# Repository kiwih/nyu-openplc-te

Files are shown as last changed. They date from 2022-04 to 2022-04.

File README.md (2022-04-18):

# NYU OpenPLC Trojan Edition (TE)

This repository contains NYU's implementation of the OpenPLC hardware. 
Several important modifications are included, notably, a socket for a second
microcontroller (a Raspberry Pi Pico) which can act as a 'Hardware Trojan'.
Different Hardware Trojan capabilities can be enabled and disabled depending on the configuration of a number of jumpers located around the PCB.

There are a small number of known issues with the v0.1 board. 
These include the usage of a now-obsolete accelerometer, and poor component
choice for on-board power measurement circuitry.

These will be remedied for version 0.2 of this work.

This PCB was used in the paper,
"Detecting Hardware Trojans in PCBs Using Side Channel Loopbacks"
by Hammond Pearce, Virinchi Roy Surabhi, Prashanth Krishnamurthy,
Joshua Trujillo, Ramesh Karri, and Farshad Khorrami.
Published in IEEE TVLSI, 2022.

## Repository contents

`/final-outputs-v0.1` - this includes the schematic files, BOM CSVs, PDF layout files, and final production gerbers of the PCB manufactured for use in the paper.

`/kicad-files-v0.1` - this contains the KiCAD project used to make the project.

## New versions of the PCB

Newer versions (v0.2 and above) are currently under active development and will be released through this repository upon validation.

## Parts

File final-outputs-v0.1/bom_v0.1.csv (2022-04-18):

Designator | Comment | Footprint | Manufacturer | Vendor
C1 | 220uF | Capacitor_SMD:CP_Elec_10x10 |  | C134519
C2 | 220uF | Capacitor_SMD:CP_Elec_10x10 |  | C134519
C3 | 180uF | Capacitor_SMD:CP_Elec_6.3x7.7 |  | C413657
C4 | 180uF | Capacitor_SMD:CP_Elec_6.3x7.7 |  | C413657
C5 | 4.7uF | Capacitor_SMD:C_0805_2012Metric |  | C1779
C6 | 100nF | Capacitor_SMD:C_0805_2012Metric |  | C49678
C7 | 100nF | Capacitor_SMD:C_0805_2012Metric |  | C49678
C8 | 1nF | Capacitor_SMD:C_0805_2012Metric |  | C46653
C9 | 100nF | Capacitor_SMD:C_0805_2012Metric |  | C49678
C10 | 1nF | Capacitor_SMD:C_0805_2012Metric |  | C46653
C11 | 100nF | Capacitor_SMD:C_0805_2012Metric |  | C49678
C12 | 100nF | Capacitor_SMD:C_0805_2012Metric |  | C49678
C13 | 100nF | Capacitor_SMD:C_0805_2012Metric |  | C49678
C14 | 100nF | Capacitor_SMD:C_0805_2012Metric |  | C49678
C15 | 100nF | Capacitor_SMD:C_0805_2012Metric |  | C49678
C16 | 100nF | Capacitor_SMD:C_0805_2012Metric |  | C49678
C17 | 100nF | Capacitor_SMD:C_0805_2012Metric |  | C49678
C18 | 4.7uf | Capacitor_SMD:C_0805_2012Metric |  | C1779
C19 | 1nF | Capacitor_SMD:C_0805_2012Metric |  | C46653
C20 | 100n | Capacitor_SMD:C_0805_2012Metric |  | C49678
C21 | 100nF | Capacitor_SMD:C_0805_2012Metric |  | C49678
C22 | 100n | Capacitor_SMD:C_0805_2012Metric |  | C49678
C23 | 100nf | Capacitor_SMD:C_0805_2012Metric |  | C49678
C24 | 22uf | Capacitor_SMD:C_0805_2012Metric |  | C45783
C25 | 22uf | Capacitor_SMD:C_0805_2012Metric |  | C45783
C26 | 4.7uF | Capacitor_SMD:C_0805_2012Metric |  | C1779
C27 | 100nF | Capacitor_SMD:C_0805_2012Metric |  | C49678
D1 | B5819W | Diode_SMD:D_SOD-123 |  | C8598
D2 | B5819W | Diode_SMD:D_SOD-123 |  | C8598
D3 | B5819W | Diode_SMD:D_SOD-123 |  | C8598
D4 | B5819W | Diode_SMD:D_SOD-123 |  | C8598
D5 | B5819W | Diode_SMD:D_SOD-123 |  | C8598
D6 | SS54 | Diode_SMD:D_SMA |  | C22452
D7 | LED | LED_SMD:LED_0805_2012Metric |  | C2297
D11 | LED | LED_SMD:LED_0805_2012Metric |  | C2297
D12 | LED | LED_SMD:LED_0805_2012Metric |  | C2297
D13 | LED | LED_SMD:LED_0805_2012Metric |  | C2297
D14 | LED | LED_SMD:LED_0805_2012Metric |  | C2297
D15 | LED | LED_SMD:LED_0805_2012Metric |  | C2297
D16 | LED | LED_SMD:LED_0805_2012Metric |  | C2297
D17 | LED | LED_SMD:LED_0805_2012Metric |  | C2297
D18 | LED | LED_SMD:LED_0805_2012Metric |  | C2297
D20 | LED | LED_SMD:LED_0805_2012Metric |  | C2297
D21 | LED | LED_SMD:LED_0805_2012Metric |  | C2293
D22 | LED | LED_SMD:LED_0805_2012Metric |  | C2293
K1 | G6S-2 | Relay_SMD:Relay_DPDT_Omron_G6S-2F |  | C397130
K2 | G6S-2 | Relay_SMD:Relay_DPDT_Omron_G6S-2F |  | C397130
K3 | G6S-2 | Relay_SMD:Relay_DPDT_Omron_G6S-2F |  | C397130
K4 | G6S-2 | Relay_SMD:Relay_DPDT_Omron_G6S-2F |  | C397130
L1 | 68uH | kiwih_kicad:L_10x11.5mm_H4mm |  | C497902
L2 | 3.3uH | kiwih_kicad:L_7.1x6.6_H3 |  | C207839
Q1 | 2N7002 | Package_TO_SOT_SMD:SOT-23 |  | C8545
Q2 | 2N7002 | Package_TO_SOT_SMD:SOT-23 |  | C8545
Q3 | 2N7002 | Package_TO_SOT_SMD:SOT-23 |  | C8545
Q4 | 2N7002 | Package_TO_SOT_SMD:SOT-23 |  | C8545
R1 | 1k | Resistor_SMD:R_0805_2012Metric |  | C17513
R2 | 1k | Resistor_SMD:R_0805_2012Metric |  | C17513
R3 | 1k | Resistor_SMD:R_0805_2012Metric |  | C17513
R4 | 1k | Resistor_SMD:R_0805_2012Metric |  | C17513
R5 | 120R | Resistor_SMD:R_0805_2012Metric |  | C17437
R9 | 100k | Resistor_SMD:R_0805_2012Metric |  | C17407
R10 | 100k | Resistor_SMD:R_0805_2012Metric |  | C17407
R11 | 100k | Resistor_SMD:R_0805_2012Metric |  | C17407
R12 | 100k | Resistor_SMD:R_0805_2012Metric |  | C17407
R13 | 16k | Resistor_SMD:R_0805_2012Metric |  | C17490
R14 | 16k | Resistor_SMD:R_0805_2012Metric |  | C17490
R15 | 16k | Resistor_SMD:R_0805_2012Metric |  | C17490
R16 | 16k | Resistor_SMD:R_0805_2012Metric |  | C17490
R17 | 10k | Resistor_SMD:R_0805_2012Metric |  | C17414
R18 | 10k | Resistor_SMD:R_0805_2012Metric |  | C17414
R19 | 10k | Resistor_SMD:R_0805_2012Metric |  | C17414
R20 | 10k | Resistor_SMD:R_0805_2012Metric |  | C17414
R21 | 10k | Resistor_SMD:R_0805_2012Metric |  | C17414
R22 | 10k | Resistor_SMD:R_0805_2012Metric |  | C17414
R23 | 10k | Resistor_SMD:R_0805_2012Metric |  | C17414
R24 | 10k | Resistor_SMD:R_0805_2012Metric |  | C17414
R25 | 20k | Resistor_SMD:R_0805_2012Metric |  | C4328
R26 | 20K | Resistor_SMD:R_0805_2012Metric |  | C4328
R27 | 5K | Resistor_SMD:R_0805_2012Metric |  | C4328
R28 | 5K | Resistor_SMD:R_0805_2012Metric |  | C4328
R29 | 10K | Resistor_SMD:R_0805_2012Metric |  | C17414
R30 | 10K | Resistor_SMD:R_0805_2012Metric |  | C17414
R31 | 10K | Resistor_SMD:R_0805_2012Metric |  | C17414
R32 | 10K | Resistor_SMD:R_0805_2012Metric |  | C17414
R33 | 10K | Resistor_SMD:R_0805_2012Metric |  | C17414
R34 | 10K | Resistor_SMD:R_0805_2012Metric |  | C17414
R35 | 100R | Resistor_SMD:R_0805_2012Metric |  | C17408
R36 | 100R | Resistor_SMD:R_0805_2012Metric |  | C17408
R37 | 120R | Resistor_SMD:R_0805_2012Metric |  | C17437
R38 | 120R | Resistor_SMD:R_0805_2012Metric |  | C17437
R39 | 120R | Resistor_SMD:R_0805_2012Metric |  | C17437
R40 | 120R | Resistor_SMD:R_0805_2012Metric |  | C17437
R41 | 10k | Resistor_SMD:R_0805_2012Metric |  | C17414
R42 | 10k | Resistor_SMD:R_0805_2012Metric |  | C17414
R43 | DNF | Resistor_SMD:R_0805_2012Metric
R44 | 120R | Resistor_SMD:R_0805_2012Metric |  | C17437
R45 | DNF | Resistor_SMD:R_0805_2012Metric
R46 | 120R | Resistor_SMD:R_0805_2012Metric |  | C17437
R47 | 120R | Resistor_SMD:R_0805_2012Metric |  | C17437
R48 | 120R | Resistor_SMD:R_0805_2012Metric |  | C17437
R50 | 0 | Resistor_SMD:R_0805_2012Metric |  | C17477
R51 | 10K | Resistor_SMD:R_0805_2012Metric |  | C17414
R52 | 10K | Resistor_SMD:R_0805_2012Metric |  | C17414
U1 | LM2596S-5 | Package_TO_SOT_SMD:TO-263-5_TabPin3 |  | C10002
U2 | LTV-247 | Package_SO:SOP-16_4.4x10.4mm_P1.27mm |  | C115451
U3 | ULN2003A | Package_SO:SOIC-16_3.9x9.9mm_P1.27mm |  | C7512
U4 | ADS1115IDGS | Package_SO:TSSOP-10_3x3mm_P0.5mm |  | C37593
U5 | SP3485EN | Package_SO:SOIC-8_3.9x4.9mm_P1.27mm |  | C8963
U6 | ACS712xLCTR-05B | Package_SO:SOIC-8_3.9x4.9mm_P1.27mm |  | C44471
U7 | AMS1117-3.3 | Package_TO_SOT_SMD:SOT-223-3_TabPin2 |  | C6186
U8 | ACS712xLCTR-05B | Package_SO:SOIC-8_3.9x4.9mm_P1.27mm |  | C44471
U9 | EL357N | kiwih_kicad:SOP-4_4.1x4.4mm_P2.54mm |  | C6649
U10 | ADS1115IDGS | Package_SO:TSSOP-10_3x3mm_P0.5mm |  | C37593
U11 | FXOS8700CQ | kiwih_kicad:QFN-16_5.3.5.3_3x3_Pitch0.5mm |  | C432308
U12 | ACS712xLCTR-05B | Package_SO:SOIC-8_3.9x4.9mm_P1.27mm |  | C44471

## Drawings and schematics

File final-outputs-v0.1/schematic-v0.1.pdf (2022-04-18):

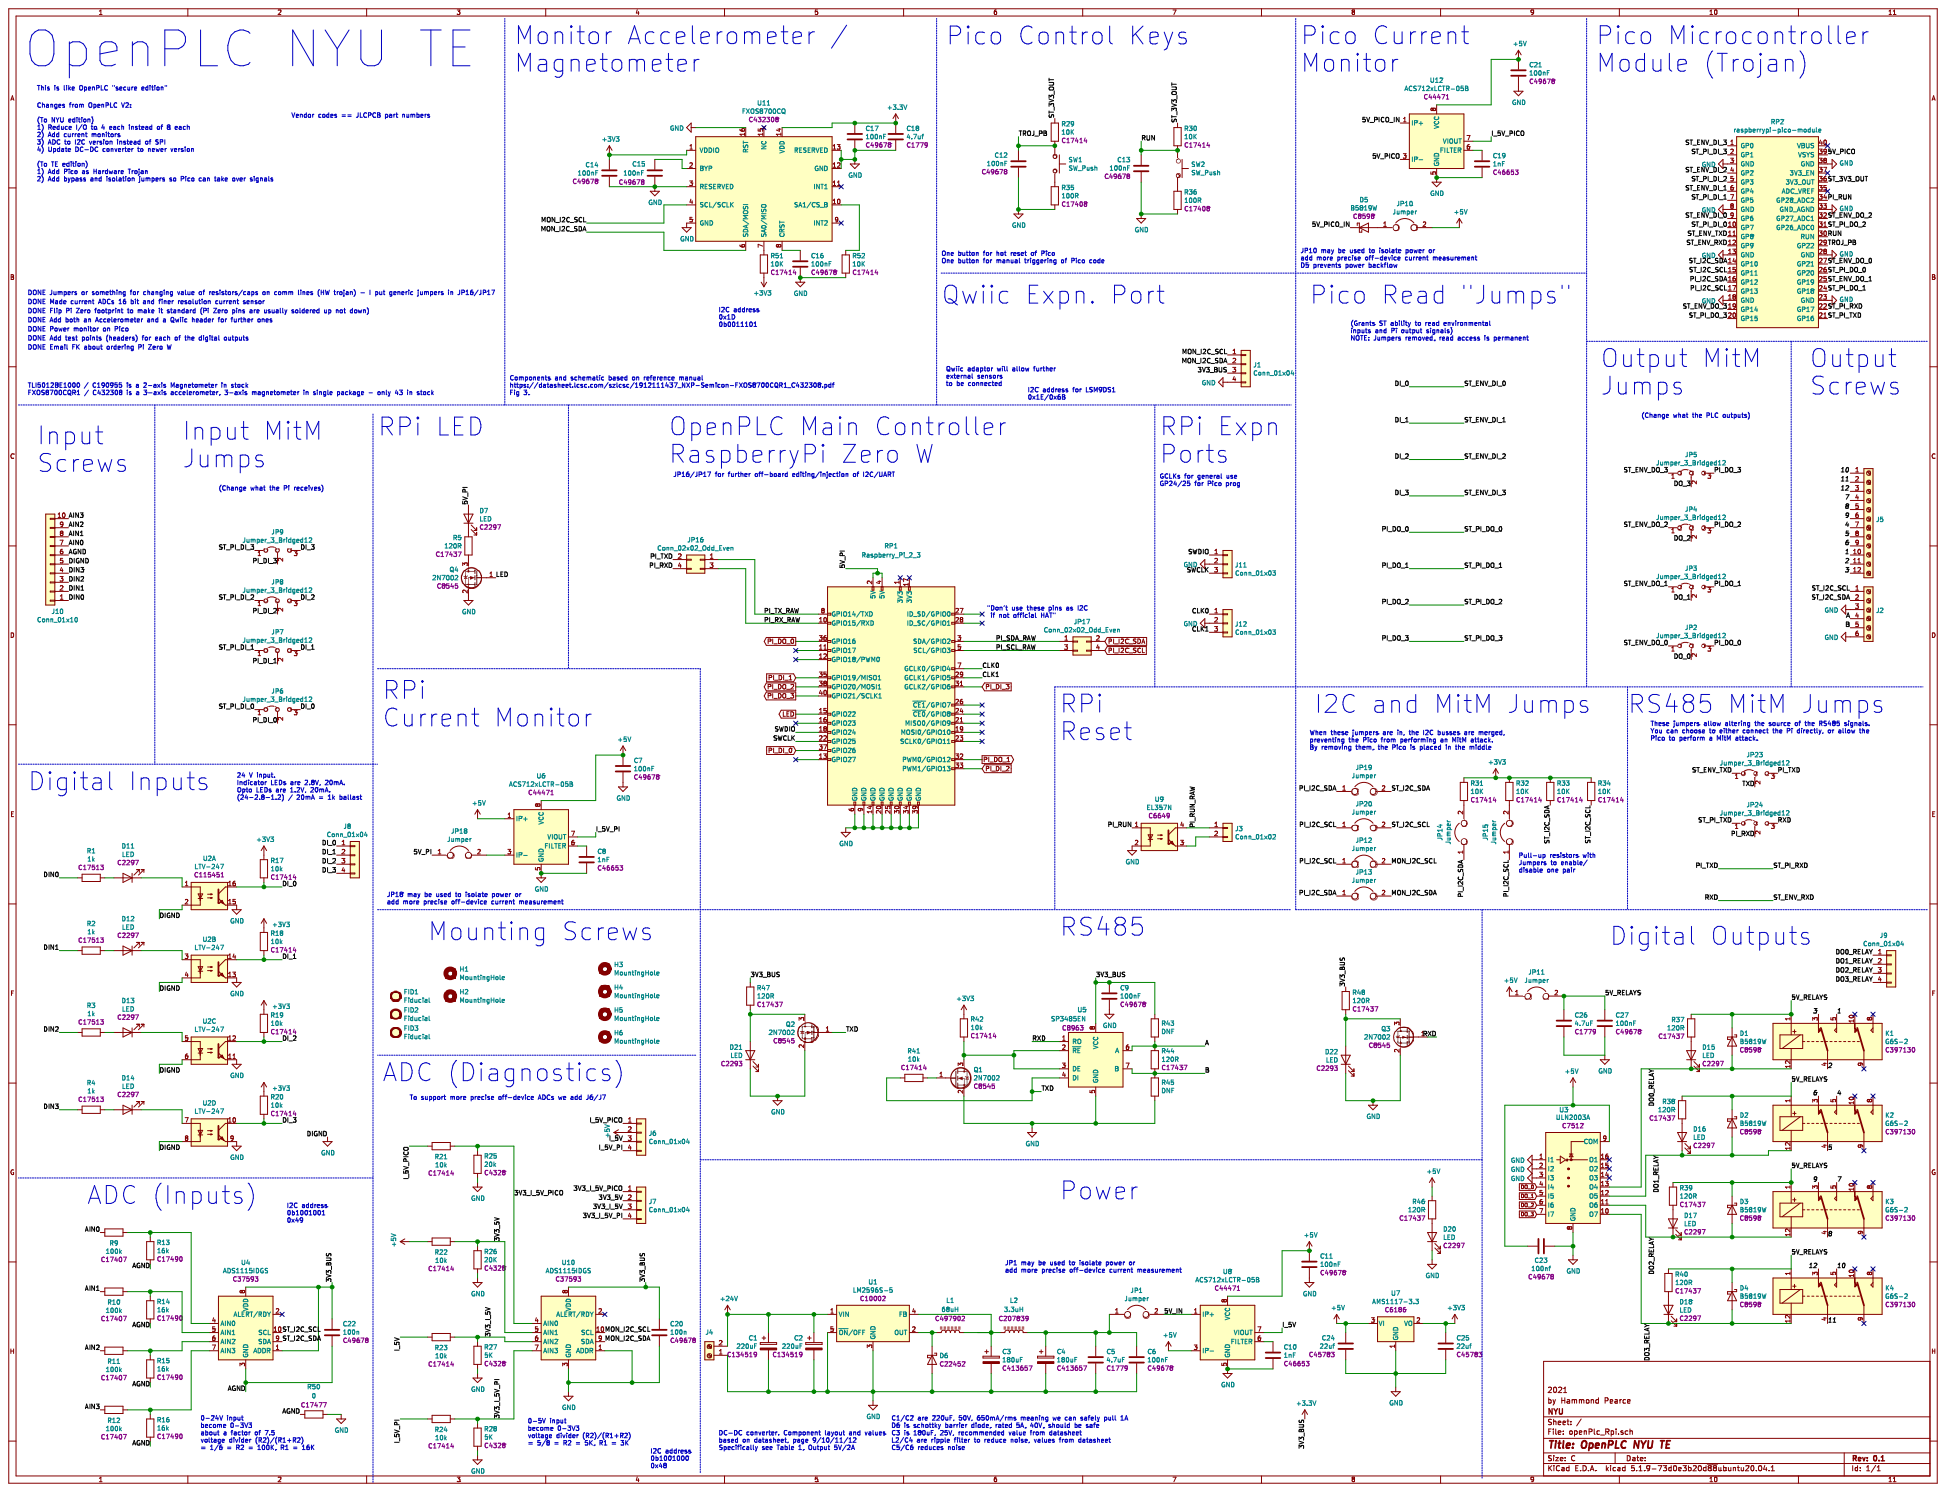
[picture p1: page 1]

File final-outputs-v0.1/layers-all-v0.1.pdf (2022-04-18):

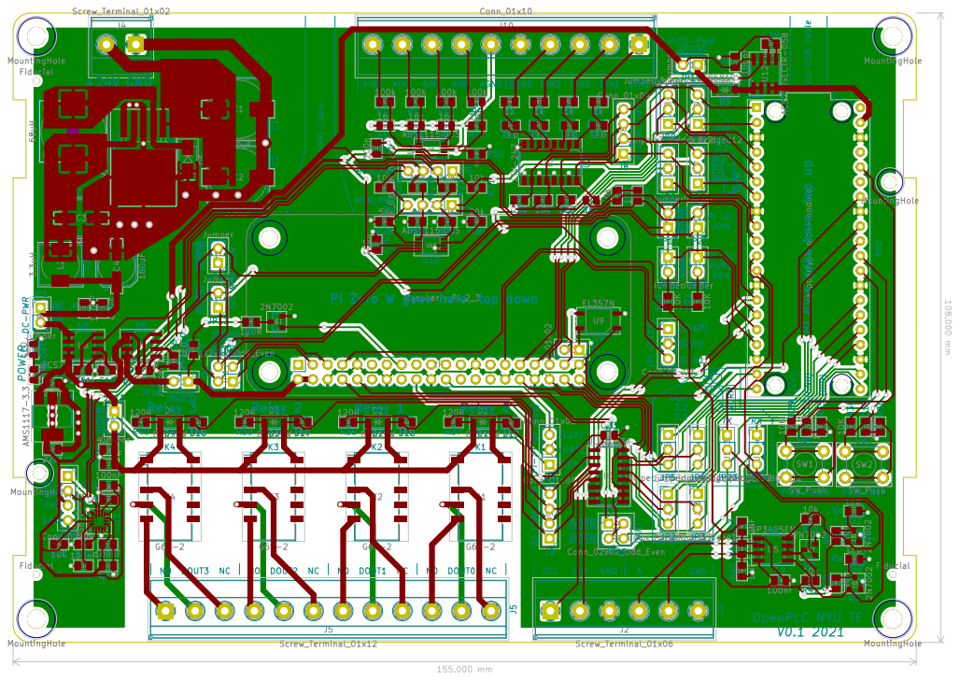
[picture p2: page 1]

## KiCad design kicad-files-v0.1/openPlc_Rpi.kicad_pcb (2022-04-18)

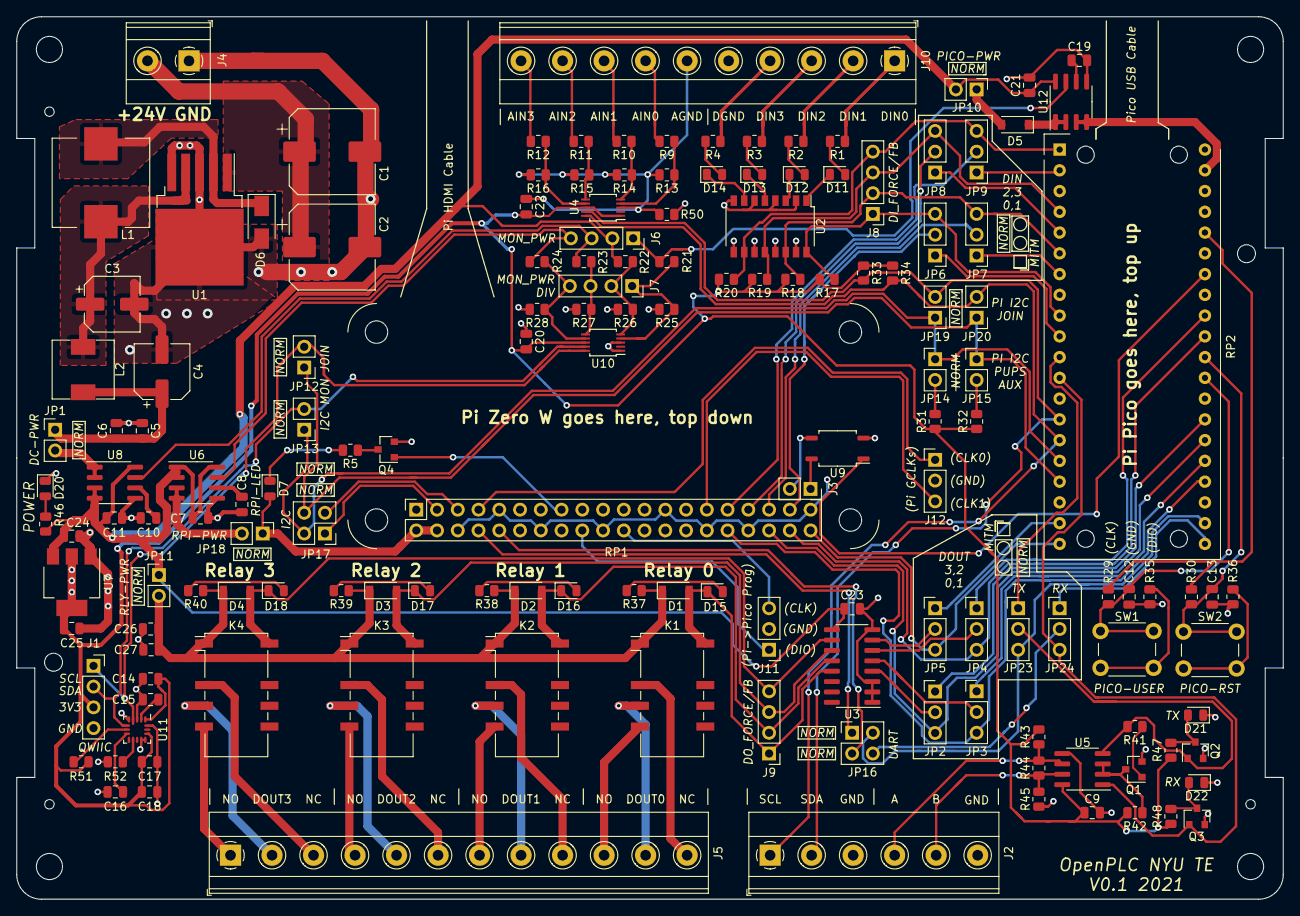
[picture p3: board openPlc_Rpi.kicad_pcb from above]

Board: 2 copper layers, 155.0 x 108.0 mm, 162 parts (0 on the bottom side), 133 nets.

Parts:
C1, C2: 220uF; CP_Elec_10x10
C3, C4: 180uF; CP_Elec_6.3x7.7
C5, C26: 4.7uF; C_0805_2012Metric
C6, C7, C9, C11, C12, C13, C14, C15, C16, C17, C21, C27: 100nF; C_0805_2012Metric
C8, C10, C19: 1nF; C_0805_2012Metric
C18: 4.7uf; C_0805_2012Metric
C20, C22: 100n; C_0805_2012Metric
C23: 100nf; C_0805_2012Metric
C24, C25: 22uf; C_0805_2012Metric
D1, D2, D3, D4, D5: B5819W; D_SOD-123
D6: SS54; D_SMA
D7, D11, D12, D13, D14, D15, D16, D17, D18, D20, D21, D22: LED; LED_0805_2012Metric
FID1, FID2, FID3: Fiducial; jlcpcb-fiducial
H1, H2: MountingHole; MountingHole_2.2mm_M2
H3, H4, H5, H6: MountingHole; MountingHole_3.2mm_M3
J1, J6, J7: Conn_01x04; PinSocket_1x04_P2.54mm_Vertical
J2: Screw_Terminal_01x06; TerminalBlock_Phoenix_MKDS-1,5-6-5.08_1x06_P5.08mm_Horizont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
J3: Conn_01x02; PinSocket_1x02_P2.54mm_Vertical
J4: Screw_Terminal_01x02; TerminalBlock_Phoenix_MKDS-1,5-2-5.08_1x02_P5.08mm_Horizont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
J5: Screw_Terminal_01x12; TerminalBlock_Phoenix_MKDS-1,5-12-5.08_1x12_P5.08mm_Horizon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
J8, J9: Conn_01x04; PinHeader_1x04_P2.54mm_Vertical
J10: Conn_01x10; TerminalBlock_Phoenix_MKDS-1,5-10-5.08_1x10_P5.08mm_Horizon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
J11, J12: Conn_01x03; PinHeader_1x03_P2.54mm_Vertical
JP1, JP10, JP11, JP12, JP13, JP14, JP15, JP18, JP19, JP20: Jumper; PinHeader_1x02_P2.54mm_Vertical
JP2, JP3, JP4, JP5, JP6, JP7, JP8, JP9, JP23, JP24: Jumper_3_Bridged12; PinHeader_1x03_P2.54mm_Vertical
JP16, JP17: Conn_02x02_Odd_Even; PinHeader_2x02_P2.54mm_Vertical
K1, K2, K3, K4: G6S-2; Relay_DPDT_Omron_G6S-2F
L1: 68uH; L_10x11.5mm_H4mm
L2: 3.3uH; L_7.1x6.6_H3
Q1, Q2, Q3, Q4: 2N7002; SOT-23
R1, R2, R3, R4: 1k; R_0805_2012Metric
R5, R37, R38, R39, R40, R44, R46, R47, R48: 120R; R_0805_2012Metric
R9, R10, R11, R12: 100k; R_0805_2012Metric
R13, R14, R15, R16: 16k; R_0805_2012Metric
R17, R18, R19, R20, R21, R22, R23, R24, R41, R42: 10k; R_0805_2012Metric
R25: 20k; R_0805_2012Metric
R26: 20K; R_0805_2012Metric
R27, R28: 5K; R_0805_2012Metric
R29, R30, R31, R32, R33, R34, R51, R52: 10K; R_0805_2012Metric
R35, R36: 100R; R_0805_2012Metric
R43, R45: DNF; R_0805_2012Metric
R50: 0; R_0805_2012Metric
RP1: Raspberry_Pi_2_3; RPiZero-Hat
RP2: raspberrypi-pico-module
SW1, SW2: SW_Push; SW_PUSH_6mm
U1: LM2596S-5; TO-263-5_TabPin3
U2: LTV-247; SOP-16_4.4x10.4mm_P1.27mm
U3: ULN2003A; SOIC-16_3.9x9.9mm_P1.27mm
U4, U10: ADS1115IDGS; TSSOP-10_3x3mm_P0.5mm
U5: SP3485EN; SOIC-8_3.9x4.9mm_P1.27mm
U6, U8, U12: ACS712xLCTR-05B; SOIC-8_3.9x4.9mm_P1.27mm
U7: AMS1117-3.3; SOT-223-3_TabPin2
U9: EL357N; SOP-4_4.1x4.4mm_P2.54mm
U11: FXOS8700CQ; QFN-16_5.3.5.3_3x3_Pitch0.5mm

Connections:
+3V3: C9.1, C14.1, C17.1, C18.1, C20.2, C22.2, C25.1, J1.3, R17.1, R18.1, R19.1, R20.1, R31.1, R32.1, R33.1, R34.1, R42.2, R43.2, R47.1, R48.1, R51.2, U4.1, U4.8, U5.8, U7.2, U10.8, U11.1, U11.14
+5V: C7.1, C11.1, C21.1, C23.1, C24.1, J6.2, JP10.2, JP11.1, R22.2, R46.1, U3.9, U6.1, U6.2, U6.8, U7.3, U8.3, U8.4, U8.8, U12.8
+24V: C1.1, C2.1, J4.2, U1.1
/1: J5.10, K1.5
/2: J5.11, K1.4
/3: J5.12, K1.3
/3V3_5V: J7.2, R22.1, R26.1, U10.5
/3V3_I_5V: J7.3, R23.1, R27.1, U10.6
/3V3_I_5V_PI: J7.4, R24.1, R28.1, U10.7
/3V3_I_5V_PICO: J7.1, R21.1, R25.1, U10.4
/4: J5.7, K2.5
/5: J5.8, K2.4
/5V_IN: JP1.2, U8.1, U8.2
/5V_PI: D7.2, JP18.1, RP1.2, RP1.4
/5V_PICO: RP2.39, U12.3, U12.4
/5V_PICO_IN: D5.1, U12.1, U12.2
/5V_RELAYS: C26.1, C27.1, D1.1, D2.1, D3.1, D4.1, JP11.2, K1.1, K2.1, K3.1, K4.1, R37.1, R38.1, R39.1, R40.1
/6: J5.9, K2.3
/7: J5.4, K3.5
/8: J5.5, K3.4
/9: J5.6, K3.3
/10: J5.1, K4.5
/11: J5.2, K4.4
/12: J5.3, K4.3
/A: J2.4, R43.1, R44.2, U5.6
/AGND: C22.1, J10.6, R13.2, R14.2, R15.2, R16.2, R50.1, U4.3
/AIN0: J10.7, R9.2
/AIN1: J10.8, R10.2
/AIN2: J10.9, R11.2
/AIN3: J10.10, R12.2
/B: J2.5, R44.1, R45.2, U5.7
/CLK0: J12.1, RP1.7
/CLK1: J12.3, RP1.29
/DIN0: J10.1, R1.2
/DIN1: J10.2, R2.2
/DIN2: J10.3, R3.2
/DIN3: J10.4, R4.2
/DI_0: J8.1, JP6.3, R17.2, RP2.9, U2.16
/DI_1: J8.2, JP7.3, R18.2, RP2.6, U2.14
/DI_2: J8.3, JP8.3, R19.2, RP2.4, U2.12
/DI_3: J8.4, JP9.3, R20.2, RP2.1, U2.10
/DO0_RELAY: D1.2, D15.1, J9.1, K1.12, U3.13
/DO1_RELAY: D2.2, D16.1, J9.2, K2.12, U3.12
/DO2_RELAY: D3.2, D17.1, J9.3, K3.12, U3.11
/DO3_RELAY: D4.2, D18.1, J9.4, K4.12, U3.10
/I_5V: J6.3, R23.2, U8.7
/I_5V_PI: J6.4, R24.2, U6.7
/I_5V_PICO: J6.1, R21.2, U12.7
/MON_I2C_SCL: J1.1, JP12.2, U10.10, U11.4
/MON_I2C_SDA: J1.2, JP13.2, U10.9, U11.6
/PI_RUN: RP2.34, U9.1
/PI_RUN_RAW: J3.1, U9.4
/PI_RXD: JP16.4, JP24.2
/PI_RX_RAW: JP16.3, RP1.10
/PI_SCL_RAW: JP17.3, RP1.5
/PI_SDA_RAW: JP17.1, RP1.3
/PI_TXD: JP16.2, JP23.3, RP2.22
/PI_TX_RAW: JP16.1, RP1.8
/RUN: C13.2, R30.2, RP2.30, SW2.1
/RXD: JP24.3, Q3.1, RP2.12, U5.1
/ST_3V3_OUT: R29.1, R30.1, RP2.36
/ST_ENV_DO_0: JP2.1, RP2.27
/ST_ENV_DO_1: JP3.1, RP2.25
/ST_ENV_DO_2: JP4.1, RP2.32
/ST_ENV_DO_3: JP5.1, RP2.19
/ST_ENV_TXD: JP23.1, RP2.11
/ST_I2C_SCL: J2.1, JP20.2, R34.2, RP2.15, U4.10
/ST_I2C_SDA: J2.2, JP19.2, R33.2, RP2.14, U4.9
/ST_PI_DI_0: JP6.1, RP2.10
/ST_PI_DI_1: JP7.1, RP2.7
/ST_PI_DI_2: JP8.1, RP2.5
/ST_PI_DI_3: JP9.1, RP2.2
/ST_PI_TXD: JP24.1, RP2.21
/SWCLK: J11.3, RP1.22
/SWDIO: J11.1, RP1.18
/TROJ_PB: C12.2, R29.2, RP2.29, SW1.1
/TXD: JP23.2, Q2.1, R41.2, U5.4
DO_0: JP2.2, U3.4
DO_1: JP3.2, U3.5
DO_2: JP4.2, U3.6
DO_3: JP5.2, U3.7
GND: C1.2, C2.2, C3.2, C4.2, C5.2, C6.2, C7.2, C8.2, C9.2, C10.2, C11.2, C12.1, C13.1, C14.2, C15.2, C16.2, C17.2, C18.2, C19.2, C20.1, C21.2, C23.2, C24.2, C25.2, C26.2, C27.2, D6.2, D20.1, D21.1, D22.1, J1.4, J2.3, J2.6, J4.1, J10.5, J11.2, J12.2, Q1.2, Q2.2, Q3.2, Q4.2, R25.2, R26.2, R27.2, R28.2, R35.2, R36.2, R45.1, R50.2, R52.2, RP1.6, RP1.9, RP1.14, RP1.20, RP1.25, RP1.30, RP1.34, RP1.39, RP2.3, RP2.8, RP2.13, RP2.18, RP2.23, RP2.28, RP2.33, RP2.38, U1.3, U1.5, U2.2, U2.4, U2.6, U2.8, U2.9, U2.11, U2.13, U2.15, U3.1, U3.2, U3.3, U3.8, U5.5, U6.5, U7.1, U8.5, U9.2, U10.1, U10.3, U11.3, U11.5, U11.12, U11.13, U11.16, U12.5
LED: Q4.1, RP1.15
unnamed: C3.1, L1.2, L2.1, U1.4
unnamed: C4.1, C5.1, C6.1, JP1.1, L2.2
unnamed: C8.1, U6.6
unnamed: C10.1, U8.6
unnamed: C15.1, U11.2
unnamed: C16.1, U11.8
unnamed: C19.1, U12.6
unnamed: D5.2, JP10.1
unnamed: D6.1, L1.1, U1.2
unnamed: D7.1, R5.1
unnamed: D11.1, U2.1
unnamed: D11.2, R1.1
unnamed: D12.1, U2.3
unnamed: D12.2, R2.1
unnamed: D13.1, U2.5
unnamed: D13.2, R3.1
unnamed: D14.1, U2.7
unnamed: D14.2, R4.1
unnamed: D15.2, R37.2
unnamed: D16.2, R38.2
unnamed: D17.2, R39.2
unnamed: D18.2, R40.2
unnamed: D20.2, R46.2
unnamed: D21.2, Q2.3, R47.2
unnamed: D22.2, Q3.3, R48.2
unnamed: J3.2, U9.3
unnamed: JP14.2, R31.2
unnamed: JP15.2, R32.2
unnamed: JP18.2, U6.3, U6.4
unnamed: Q1.1, R41.1
unnamed: Q1.3, R42.1, U5.2, U5.3
unnamed: Q4.3, R5.2
unnamed: R10.1, R14.1, U4.5
unnamed: R11.1, R15.1, U4.6
unnamed: R12.1, R16.1, U4.7
unnamed: R9.1, R13.1, U4.4
unnamed: R35.1, SW1.2
unnamed: R36.1, SW2.2
unnamed: R51.1, U11.7
unnamed: R52.1, U11.10
PI_DI_0: JP6.2, RP1.37
PI_DI_1: JP7.2, RP1.35
PI_DI_2: JP8.2, RP1.33
PI_DI_3: JP9.2, RP1.31
PI_DO_0: JP2.3, RP1.36, RP2.26
PI_DO_1: JP3.3, RP1.32, RP2.24
PI_DO_2: JP4.3, RP1.38, RP2.31
PI_DO_3: JP5.3, RP1.40, RP2.20
PI_I2C_SCL: JP12.1, JP15.1, JP17.4, JP20.1, RP2.17
PI_I2C_SDA: JP13.1, JP14.1, JP17.2, JP19.1, RP2.16
